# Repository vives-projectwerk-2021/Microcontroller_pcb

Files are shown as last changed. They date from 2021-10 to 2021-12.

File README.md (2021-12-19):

# Microcontroller_pcb

Kicad files for our microcontroller pcb

## Schematic

You can see the updated schematic of our main board in the picture below
Schematic

## Pictures

| Front | Back |
|---|---|
|In this picture you can see the front of the pcb|In this picture you can see the back of the pcb
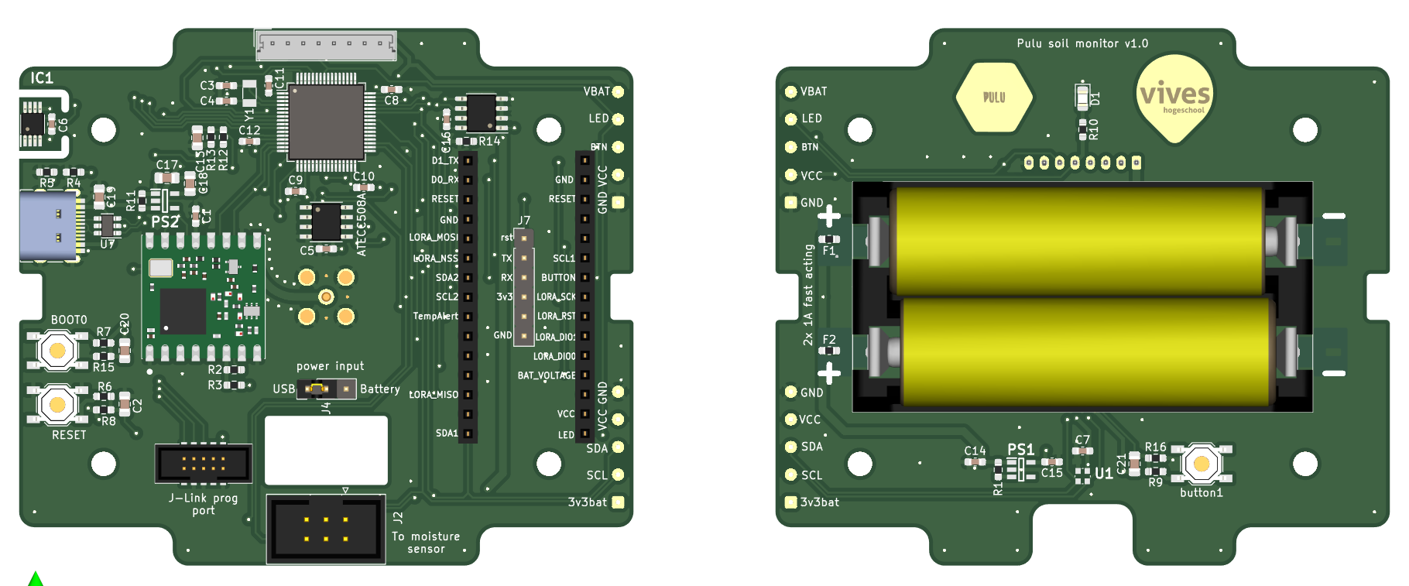
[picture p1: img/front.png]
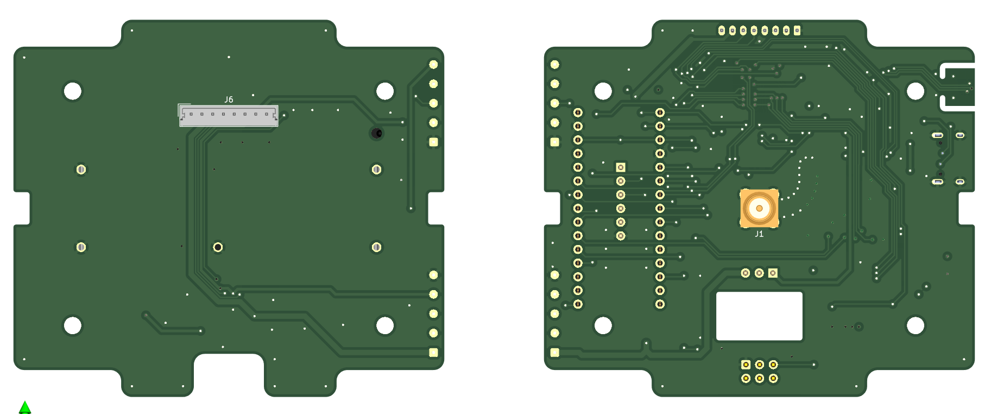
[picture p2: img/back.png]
| |  |

## Components

- STM32L476RGT

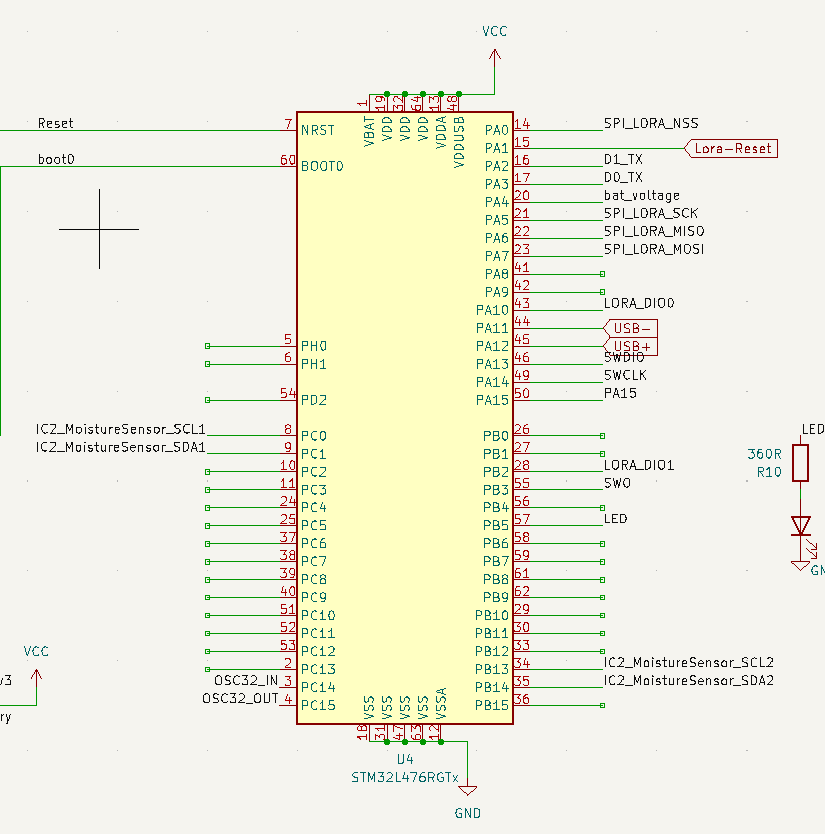
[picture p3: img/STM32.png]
µC


- 32768 Crystal

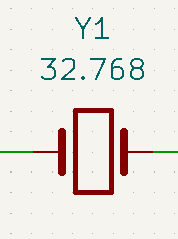
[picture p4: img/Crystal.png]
Crystal


- ESD Protection(USBLC6-2SC6)

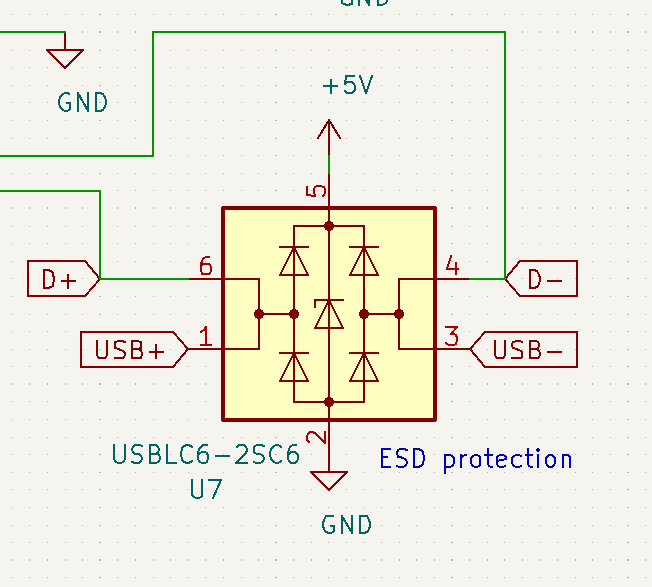
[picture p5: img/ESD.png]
ESD


- L432KC pin layout

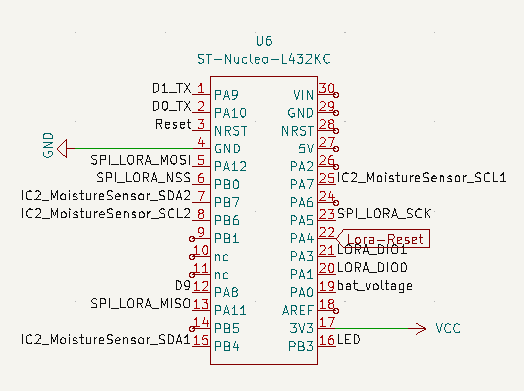
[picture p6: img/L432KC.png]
L432KC


- Cryptochip (ATTEC508A)

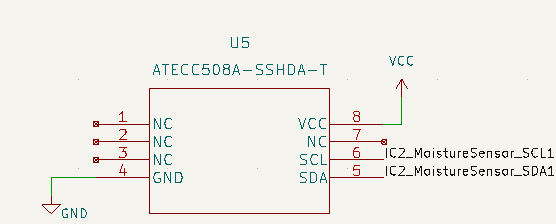
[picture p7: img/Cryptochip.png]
Cryptochip


- Batteryholder(1013)

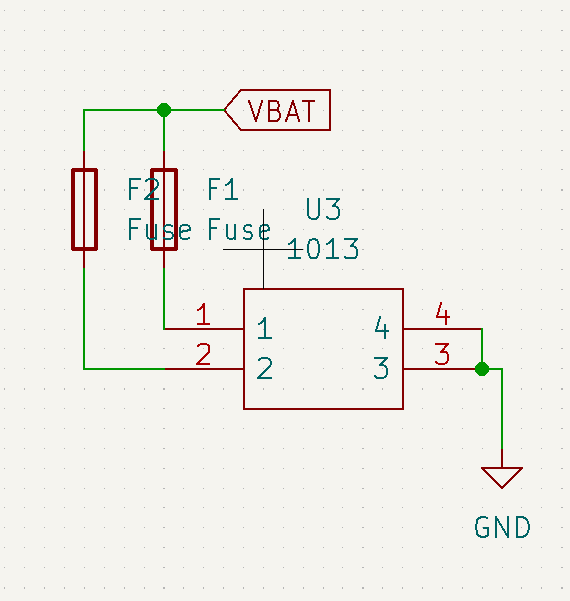
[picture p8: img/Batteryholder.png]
Batteryholder


- LoraModule (RFM95W)

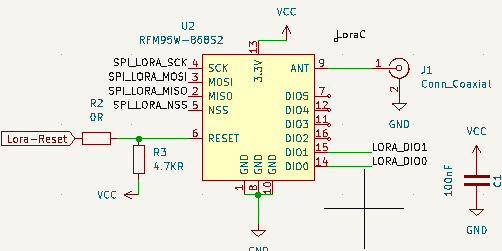
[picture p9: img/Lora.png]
Lora


- Lichtsensor (LTR-329ALS)

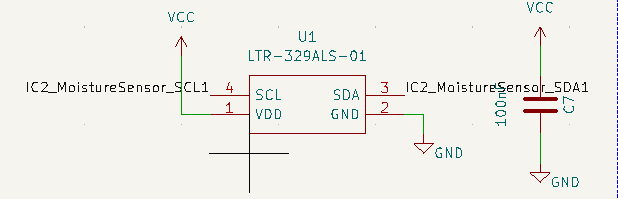
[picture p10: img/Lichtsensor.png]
Lichtsensor


- 2x Button switch SMD

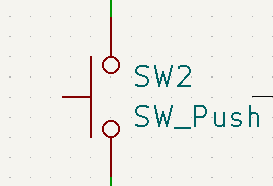
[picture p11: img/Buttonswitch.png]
Button


- 18x 100nF (0603) condensatoren

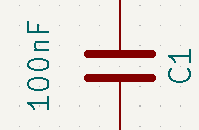
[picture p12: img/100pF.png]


- 2x 4pf (0603) Condensator bij crystal

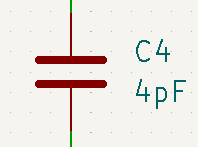
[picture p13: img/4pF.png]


- LED SMD (0805)

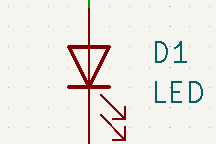
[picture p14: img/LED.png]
LED


- 2x Fuse (0603)

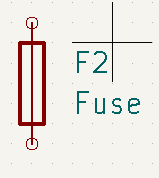
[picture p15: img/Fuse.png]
Fuse


- Temperaturesensor TCN75AVUA713-VAO

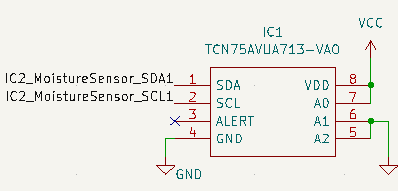
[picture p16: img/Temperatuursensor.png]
Temp


- EEPROM geheugen 24AA64T

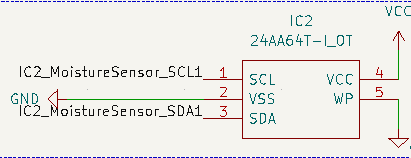
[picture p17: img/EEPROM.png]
EEPROM


- Connector Antenne SMA_Amphenol

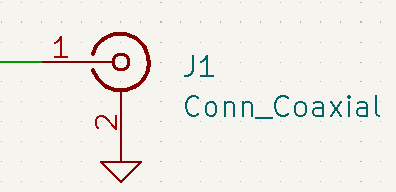
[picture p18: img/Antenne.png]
Antenne


- Connector voor moisture 2x03 2.54mm

Connector

- USB-C Connector 2.0 Type-c-31-m-12

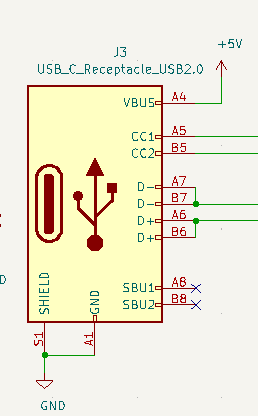
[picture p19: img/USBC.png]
USBC


- Connector voor batterij 1x03 2.54mm

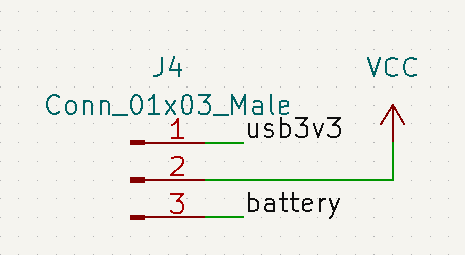
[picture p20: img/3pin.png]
3pin


- 2x Connector Molex 1x08 2.00mm

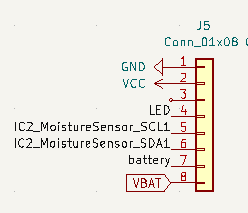
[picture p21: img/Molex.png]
Molex


- SWD Programming port (20021521-00010T1LF)

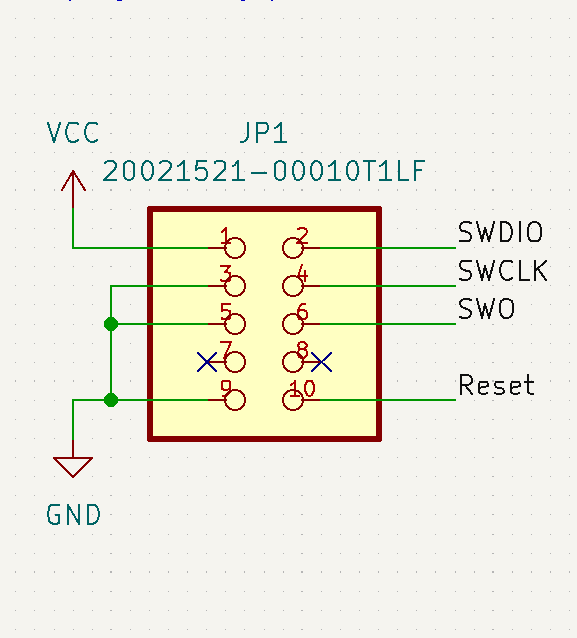
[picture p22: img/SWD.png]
SWD


- 2x LDO (PS1 S-1318B33-M5T1U4)

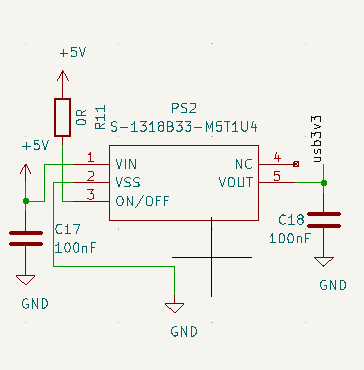
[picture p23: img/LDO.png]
LDO


- 1x 4.7kΩ

R

- 2x 5.1kΩ

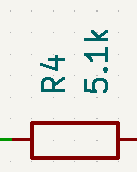
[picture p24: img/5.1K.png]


- 3x 360Ω

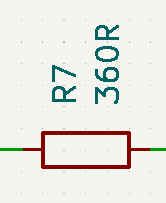
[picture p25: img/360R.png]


- 2x 100kΩ

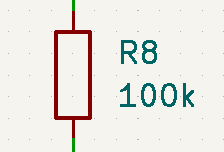
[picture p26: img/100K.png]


- 1x 220kΩ

R

- 1x 330kΩ

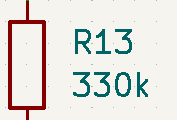
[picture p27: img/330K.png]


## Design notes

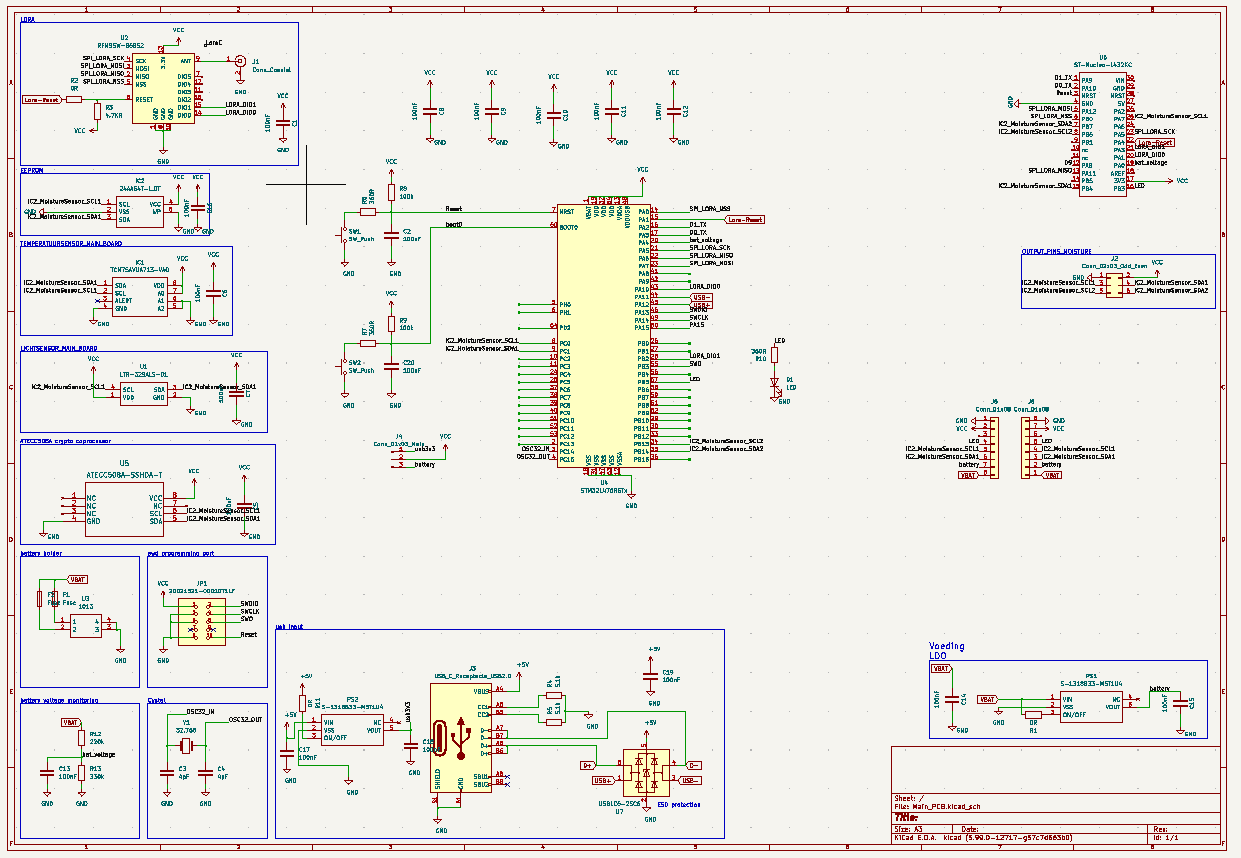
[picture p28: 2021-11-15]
img/Schematic.png

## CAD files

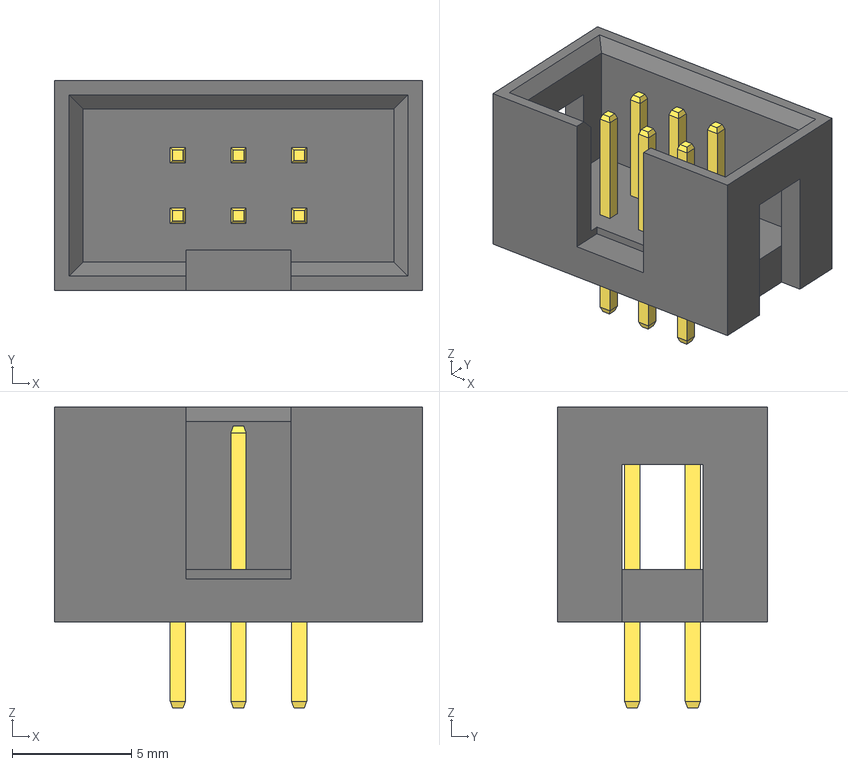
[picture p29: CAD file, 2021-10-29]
3d models/DS1013-6S (IDC-6MS CONNFLY).stp
15.4 x 8.80 x 12.6 mm

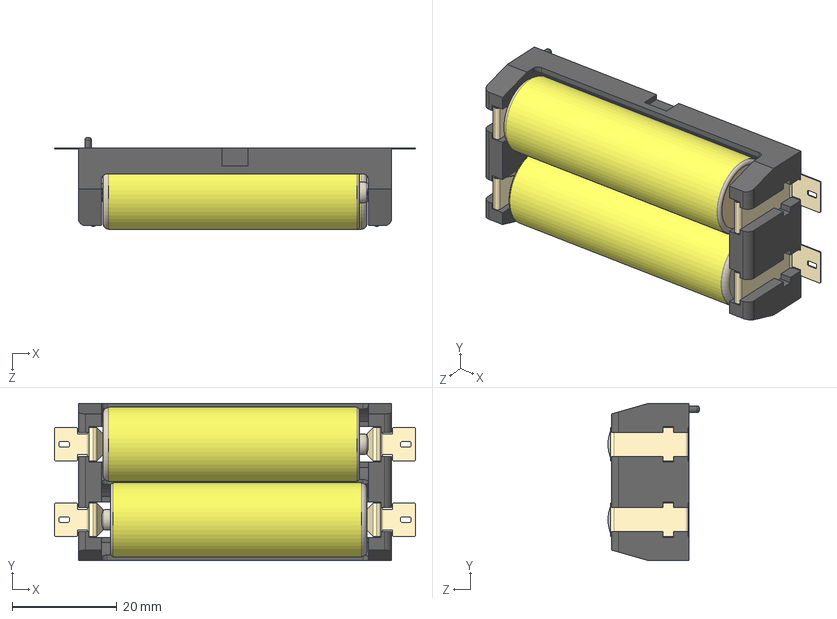
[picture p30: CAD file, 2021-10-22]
3d models/BatteryHolder_Keystone_1012_2xAA.step
69.0 x 30.0 x 17.6 mm
AAx2 SMT 422 Battery Holder
connector x 4
AA Battery_new x 2
bung_battery x 2
grafite_electrode x 2
cap x 2

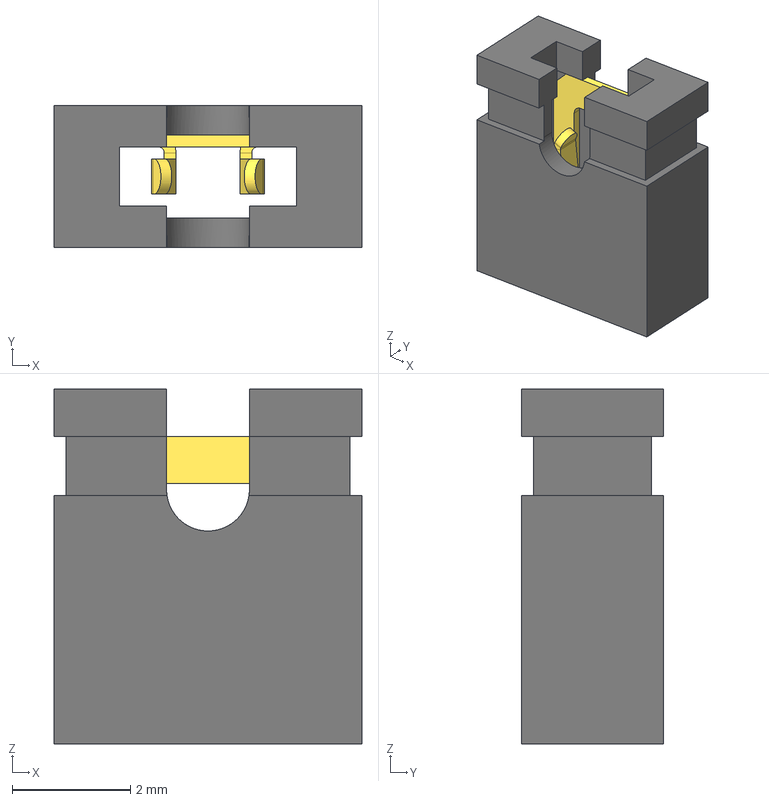
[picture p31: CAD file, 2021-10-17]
3d models/Jumper.step
5.20 x 2.40 x 6.00 mm

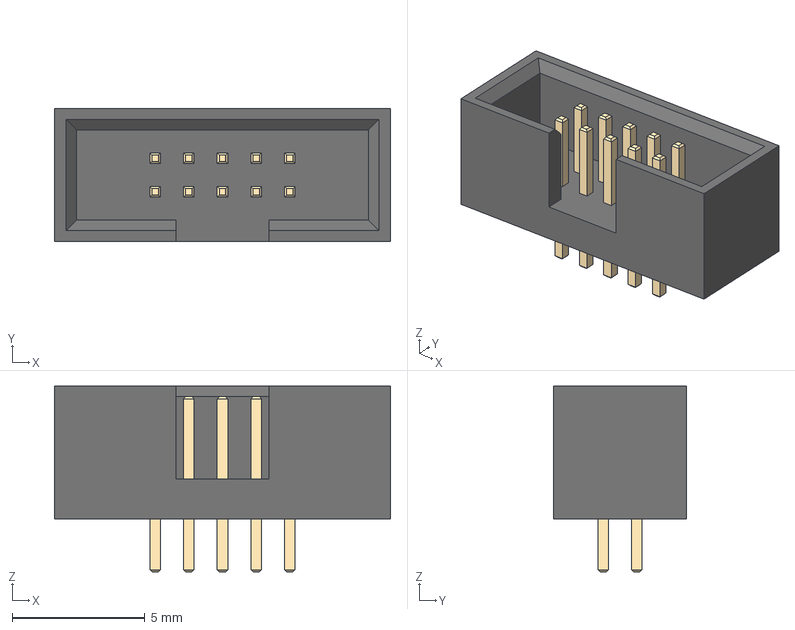
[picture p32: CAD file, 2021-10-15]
3d models/JTAG - 1.27mm - 2x5 v3.step
12.7 x 5.00 x 7.00 mm

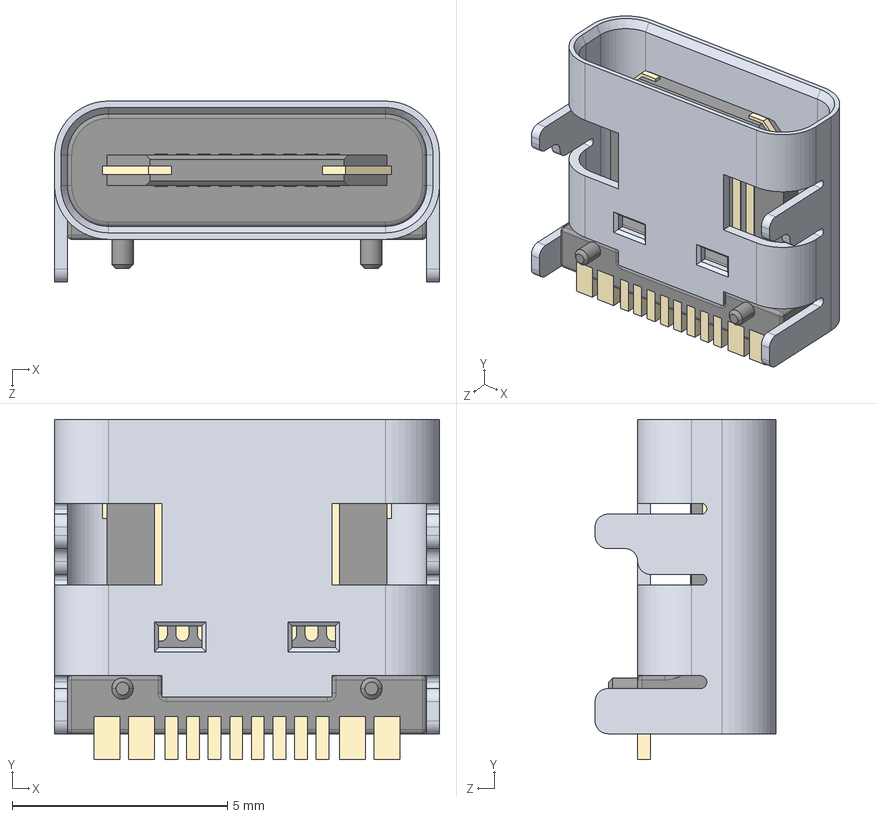
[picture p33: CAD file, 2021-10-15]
3d models/USB Type C Port (SMD Type).STEP
8.94 x 7.90 x 4.20 mm

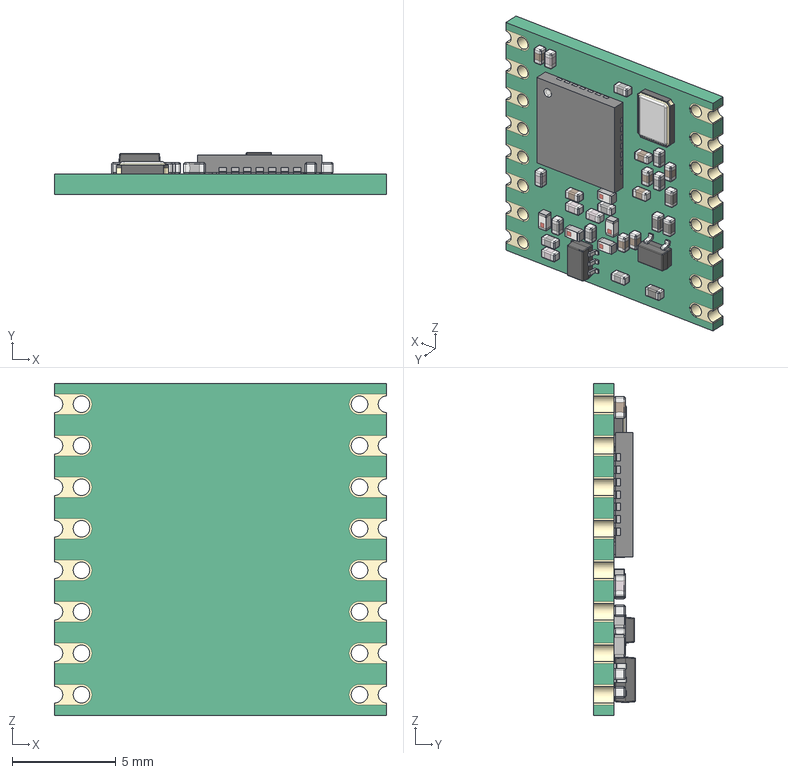
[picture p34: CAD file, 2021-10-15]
3d models/RFM95 LoRa v15.step
16.0 x 2.04 x 16.0 mm
QFN 28
SMD Crystal
CAP 0403 x 8
CAP Ceramic 0403 x 8
Res 0403 x 4
CAP ML 0403 x 5
SOT-323
Inductor SMD 0403 x 5
SOT-363

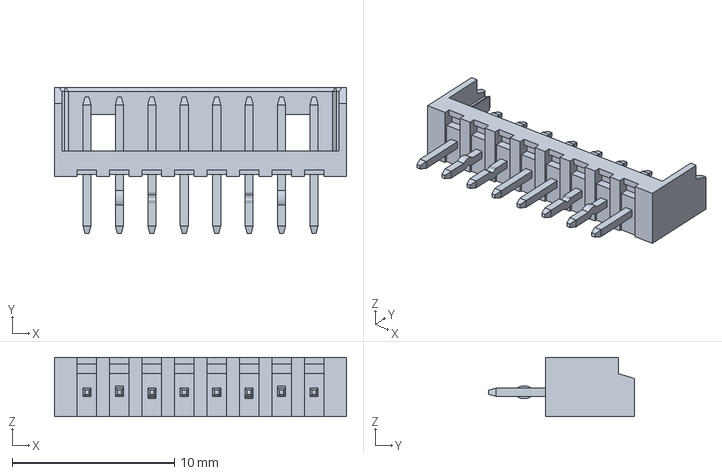
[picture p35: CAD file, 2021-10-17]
3d models/532530870.step
18.0 x 9.00 x 3.65 mm

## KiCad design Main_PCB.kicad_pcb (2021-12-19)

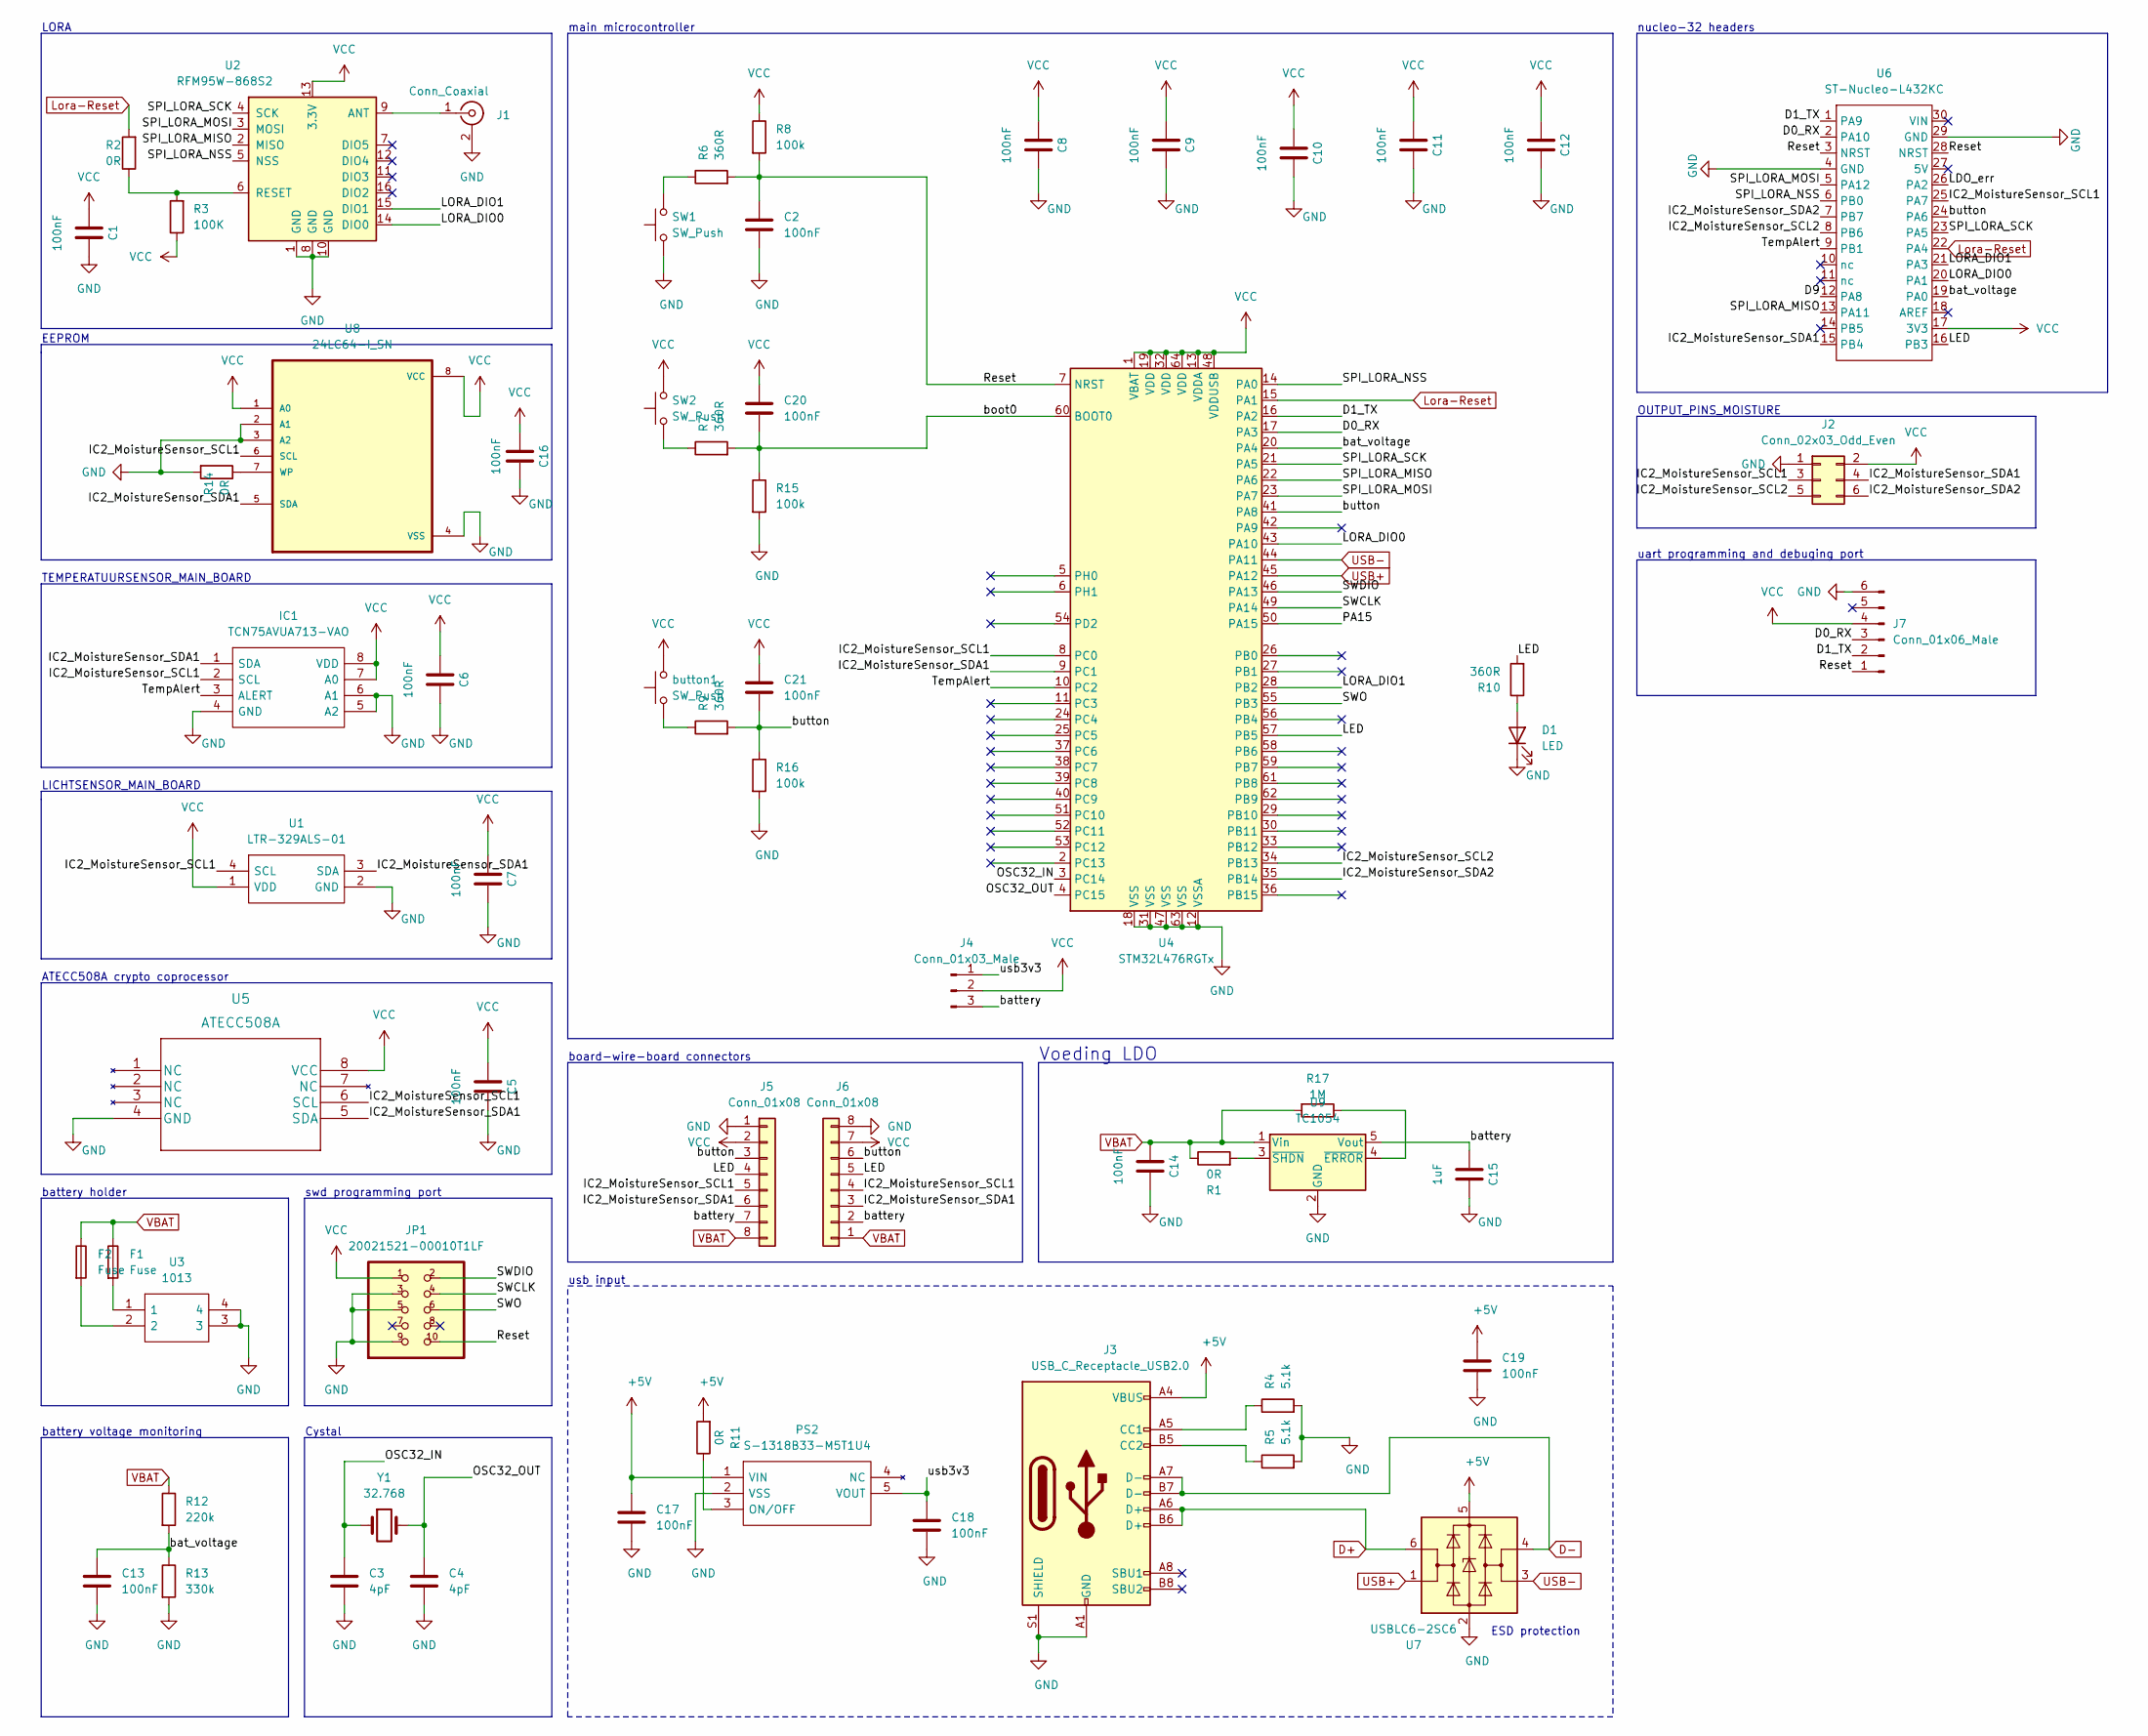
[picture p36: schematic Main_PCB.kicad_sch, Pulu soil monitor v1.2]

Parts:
C1, C2, C5, C6, C7, C8, C9, C10, C11, C12, C13, C14, C16, C17, C18, C19, C20, C21: 100nF; C_0603_1608Metric_Pad1.08x0.95mm_HandSolder
C3, C4: 4pF; C_0603_1608Metric_Pad1.08x0.95mm_HandSolder
C15: 1uF; C_0805_2012Metric_Pad1.18x1.45mm_HandSolder
D1: LED; LED_0805_2012Metric_Pad1.15x1.40mm_HandSolder
F1, F2: Fuse; Fuse_0603_1608Metric_Pad1.05x0.95mm_HandSolder
IC1: TCN75AVUA713-VAO; SOP65P490X110-8N; Manufacturer_Part_Number TCN75AVUA713-VAO; Mouser Part Number 579-TCN75AVUA713-VAO
J1: Conn_Coaxial; SMA_Amphenol_901-144_Vertical
J2: Conn_02x03_Odd_Even; IDC-Header_2x03_P2.54mm_Vertical
J3: USB_C_Receptacle_USB2.0; USB_C_Receptacle_HRO_TYPE-C-31-M-12
J4: Conn_01x03_Male; PinHeader_1x03_P2.54mm_Vertical
J5, J6: Conn_01x08; Molex_Micro-Latch_53253-0870_1x08_P2.00mm_Vertical
J7: Conn_01x06_Male; PinHeader_1x06_P2.54mm_Vertical
JP1: 20021521-00010T1LF
PS2: S-1318B33-M5T1U4; SOT95P275X130-5N; Manufacturer_Part_Number S-1318B33-M5T1U4; Mouser Part Number 628-S-1318B33-M5T1U4
R1, R2, R11, R14: 0R; R_0603_1608Metric_Pad0.98x0.95mm_HandSolder
R3: 100K; R_0603_1608Metric_Pad0.98x0.95mm_HandSolder
R4, R5: 5.1k; R_0603_1608Metric_Pad0.98x0.95mm_HandSolder
R6, R7, R9, R10: 360R; R_0603_1608Metric_Pad0.98x0.95mm_HandSolder
R8, R15, R16: 100k; R_0603_1608Metric_Pad0.98x0.95mm_HandSolder
R12: 220k; R_0603_1608Metric_Pad0.98x0.95mm_HandSolder
R13: 330k; R_0603_1608Metric_Pad0.98x0.95mm_HandSolder
R17: 1M; R_0612_1632Metric_Pad1.18x3.40mm_HandSolder
SW1, SW2: SW_Push; SW_SPST_TL3342
U1: LTR-329ALS-01; LTR329ALS01; Manufacturer_Part_Number LTR-329ALS-01; Mouser Part Number 859-LTR-329ALS-01
U2: RFM95W-868S2; XCVR_RFM95W-868S2
U3: 1013; Manufacturer_Part_Number 1013; Mouser Part Number 534-1013
U4: STM32L476RGTx; LQFP-64_10x10mm_P0.5mm
U5: ATECC508A; ATECC508A-SSHDA-T
U6: ST-Nucleo-L432KC
U7: USBLC6-2SC6; SOT-23-6
U8: 24LC64-I_SN; SOP-8_3.9x4.9mm_P1.27mm
U9: TC1054; SOT-23-5
Y1: 32.768; Crystal_SMD_3215-2Pin_3.2x1.5mm
button1: SW_Push; SW_SPST_TL3342

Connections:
+5V: C17.1, C19.1, J3.A4 (VBUS), J3.A9 (VBUS), J3.B4 (VBUS), J3.B9 (VBUS), PS2.1 (VIN), R11.2, U7.5 (VBUS)
/D0_RX: J7.3, U4.17 (PA3), U6.2 (PA10)
/D1_TX: J7.2, U4.16 (PA2), U6.1 (PA9)
/D9: U6.12 (PA8)
/IC2_MoistureSensor_SCL1: IC1.2 (SCL), J2.3, J5.5, J6.4, U1.4 (SCL), U4.8 (PC0), U5.6 (SCL), U6.25 (PA7), U8.6 (SCL)
/IC2_MoistureSensor_SCL2: J2.5, U4.34 (PB13), U6.8 (PB6)
/IC2_MoistureSensor_SDA1: IC1.1 (SDA), J2.4, J5.6, J6.3, U1.3 (SDA), U4.9 (PC1), U5.5 (SDA), U6.15 (PB4), U8.5 (SDA)
/IC2_MoistureSensor_SDA2: J2.6, U4.35 (PB14), U6.7 (PB7)
/LDO_err: U6.26 (PA2)
/LED: J5.4, J6.5, R10.2, U4.57 (PB5), U6.16 (PB3)
/LORA_DIO0: U2.14 (DIO0), U4.43 (PA10), U6.20 (PA1)
/LORA_DIO1: U2.15 (DIO1), U4.28 (PB2), U6.21 (PA3)
/OSC32_IN: C3.1, U4.3 (PC14), Y1.1
/OSC32_OUT: C4.1, U4.4 (PC15), Y1.2
/PA15: U4.50 (PA15)
/Reset: C2.1, J7.1, JP1.10, R6.2, R8.2, U4.7 (NRST), U6.3 (NRST), U6.28 (NRST)
/SPI_LORA_MISO: U2.2 (MISO), U4.22 (PA6), U6.13 (PA11)
/SPI_LORA_MOSI: U2.3 (MOSI), U4.23 (PA7), U6.5 (PA12)
/SPI_LORA_NSS: U2.5 (NSS), U4.14 (PA0), U6.6 (PB0)
/SPI_LORA_SCK: U2.4 (SCK), U4.21 (PA5), U6.23 (PA5)
/SWCLK: JP1.4, U4.49 (PA14)
/SWDIO: JP1.2, U4.46 (PA13)
/SWO: JP1.6, U4.55 (PB3)
/TempAlert: IC1.3 (ALERT), U4.10 (PC2), U6.9 (PB1)
/bat_voltage: C13.1, R12.2, R13.1, U4.20 (PA4), U6.19 (PA0)
/battery: C15.2, J4.3, J5.7, J6.2, U9.5 (Vout)
/boot0: C20.2, R7.2, R15.1, U4.60 (BOOT0)
/button: C21.2, J5.3, J6.6, R9.2, R16.1, U4.41 (PA8), U6.24 (PA6)
/usb3v3: C18.1, J4.1, PS2.5 (VOUT)
D+: J3.A6 (D+), J3.B6 (D+), U7.6 (I/O1)
D-: J3.A7 (D-), J3.B7 (D-), U7.4 (I/O2)
GND: C1.1, C2.2, C3.2, C4.2, C5.1, C6.1, C7.1, C8.1, C9.1, C10.1, C11.1, C12.1, C13.2, C14.1, C15.1, C16.1, C17.2, C18.2, C19.2, D1.1 (K), IC1.4 (GND), IC1.5 (A2), IC1.6 (A1), J1.2 (Ext), J2.1, J3.A1 (GND), J3.A12 (GND), J3.B1 (GND), J3.B12 (GND), J3.S1 (SHIELD), J5.1, J6.8, J7.6, JP1.3, JP1.5, JP1.9, PS2.2 (VSS), R4.2, R5.2, R13.2, R14.2, R15.2, R16.2, SW1.1, U1.2 (GND), U2.1 (GND), U2.8 (GND), U2.10 (GND), U3.3, U3.4, U4.12 (VSSA), U4.18 (VSS), U4.31 (VSS), U4.47 (VSS), U4.63 (VSS), U5.4 (GND), U6.4 (GND), U6.29 (GND), U7.2 (GND), U8.2 (A1), U8.3 (A2), U8.4 (VSS), U9.2 (GND)
Lora-Reset: R2.2, U4.15 (PA1), U6.22 (PA4)
unnamed: D1.2 (A), R10.1
unnamed: F1.2, U3.1
unnamed: F2.2, U3.2
unnamed: J1.1 (In), U2.9 (ANT)
unnamed: J3.A5 (CC1), R4.1
unnamed: J3.B5 (CC2), R5.1
unnamed: PS2.3 (ON/OFF), R11.1
unnamed: R1.2, U9.3 (~SHDN)
unnamed: R2.1, R3.2, U2.6 (RESET)
unnamed: R6.1, SW1.2
unnamed: R7.1, SW2.1
unnamed: R9.1, button1.1
unnamed: R14.1, U8.7 (WP)
unnamed: R17.1, U9.4 (~ERROR)
USB+: U4.45 (PA12), U7.1 (I/O1)
USB-: U4.44 (PA11), U7.3 (I/O2)
VBAT: C14.2, F1.1, F2.1, J5.8, J6.1, R1.1, R12.1, R17.2, U9.1 (Vin)
VCC: C1.2, C5.2, C6.2, C7.2, C8.2, C9.2, C10.2, C11.2, C12.2, C16.2, C20.1, C21.1, IC1.7 (A0), IC1.8 (VDD), J2.2, J4.2, J5.2, J6.7, J7.4, JP1.1, R3.1, R8.1, SW2.2, U1.1 (VDD), U2.13 (3.3V), U4.1 (VBAT), U4.13 (VDDA), U4.19 (VDD), U4.32 (VDD), U4.48 (VDDUSB), U4.64 (VDD), U5.8 (VCC), U6.17 (3V3), U8.1 (A0), U8.8 (VCC), button1.2

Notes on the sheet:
nucleo-32 headers
swd programming port
Voeding LDO
uart programming and debuging port
OUTPUT_PINS_MOISTURE
EEPROM
battery voltage monitoring
board-wire-board connectors
ESD protection
LORA
battery holder
LICHTSENSOR_MAIN_BOARD
ATECC508A crypto coprocessor
TEMPERATUURSENSOR_MAIN_BOARD
main microcontroller
Cystal
usb input

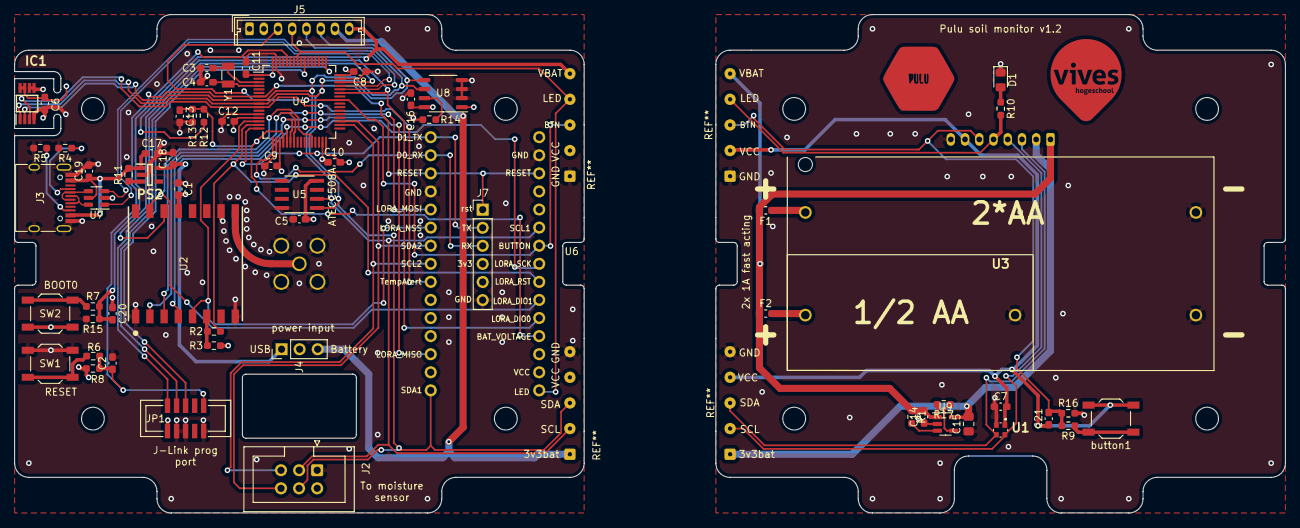
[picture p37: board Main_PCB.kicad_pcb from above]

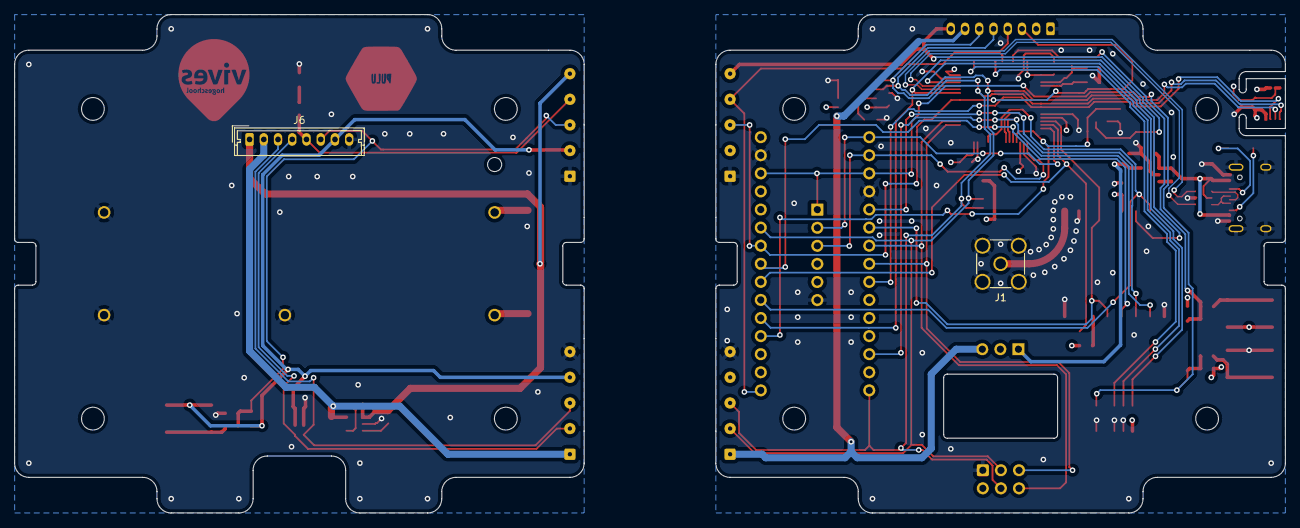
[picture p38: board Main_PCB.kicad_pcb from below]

Board: 4 copper layers, 178.5 x 70.0 mm, 72 parts (2 on the bottom side), 48 nets.

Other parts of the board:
REF1, REF2, REF3, REF4, REF5, REF6, REF7, REF8: MountingHole_3.2mm_M3

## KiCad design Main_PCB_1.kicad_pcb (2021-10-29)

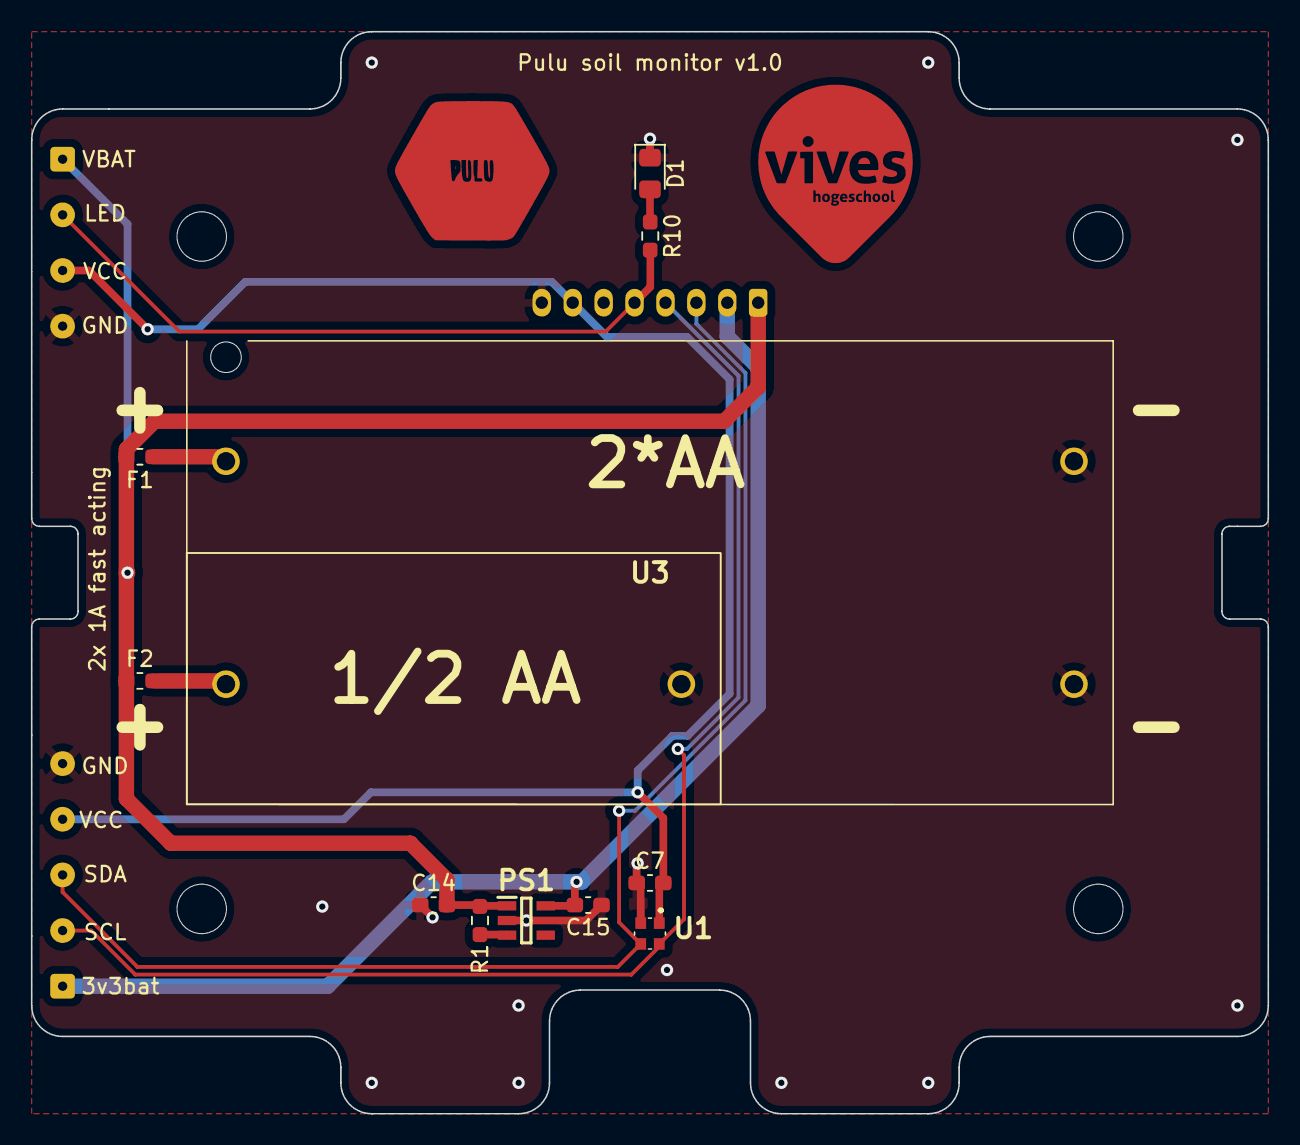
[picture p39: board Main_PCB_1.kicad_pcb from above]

Board: 2 copper layers, 80.0 x 70.0 mm, 16 parts (1 on the bottom side), 11 nets.

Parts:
C7, C14, C15: 100nF; C_0603_1608Metric_Pad1.08x0.95mm_HandSolder
D1: LED; LED_0805_2012Metric_Pad1.15x1.40mm_HandSolder
F1, F2: Fuse; Fuse_0603_1608Metric_Pad1.05x0.95mm_HandSolder
J6: Conn_01x08; Molex_Micro-Latch_53253-0870_1x08_P2.00mm_Vertical
PS1: S-1318B33-M5T1U4; SOT95P275X130-5N
R1: 0R; R_0603_1608Metric_Pad0.98x0.95mm_HandSolder
R10: 360R; R_0603_1608Metric_Pad0.98x0.95mm_HandSolder
REF5, REF6, REF7, REF8: MountingHole_3.2mm_M3
U1: LTR-329ALS-01; LTR329ALS01
U3: 1013

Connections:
/IC2_MoistureSensor_SCL1: J6.4, U1.4 (SCL)
/IC2_MoistureSensor_SDA1: J6.3, U1.3 (SDA)
/LED: J6.5, R10.2
/battery: C15.2, J6.2, PS1.5 (VOUT)
GND: C7.1, C14.1, C15.1, D1.1 (K), J6.8, PS1.2 (VSS), U1.2 (GND), U3.3, U3.4
unnamed: D1.2 (A), R10.1
unnamed: F1.2, U3.1
unnamed: F2.2, U3.2
unnamed: PS1.3 (ON/OFF), R1.2
VBAT: C14.2, F1.1, F2.1, J6.1, PS1.1 (VIN), R1.1
VCC: C7.2, J6.7, U1.1 (VDD)

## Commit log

2021-10-08 started microcontroller pcb added lora, EEPROM, ArduinoHeaders and OUTPUTPINS
    [Main_PCB.kicad_sch]
2021-10-08 fixed microcontroller
    [Main_PCB.kicad_sch]
2021-10-08 added connector for moisture sensor + connected arduino header 2 microcontroller
    [Main_PCB.kicad_sch]
2021-10-08 added battery holder and swd programming port
    [Main_PCB.kicad_pcb, Main_PCB.kicad_sch]
2021-10-11 assigned footprints
    [Main_PCB.kicad_pcb, Main_PCB.kicad_sch]
2021-10-15 did alot of the routing and pcb layout
    [Main_PCB-B_Cu.gbr, Main_PCB-B_Mask.gbr, Main_PCB-B_Paste.gbr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]
2021-10-15 added some 3d files and pcb updates
    [JTAG - 1.27mm - 2x5 v3.step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]
2021-10-16 added images to readme
    [Main_PCB.kicad_pcb]
2021-10-17 finished pcb
    [Jumper.step, Main_PCB.kicad_pcb, Main_PCB.kicad_sch]
2021-10-17 updated b2b connector
    [532530870.step, Main_PCB.kicad_pcb, Main_PCB.kicad_sch]
2021-10-18 made drc complete
    [Main_PCB.kicad_pcb, Main_PCB.kicad_sch]
2021-10-19 updated eeprom footprint
    [Main_PCB.kicad_pcb, Main_PCB.kicad_sch]
2021-10-22 separated pcb desgin into two
    [Main_PCB.kicad_pcb, Main_PCB.kicad_sch]
2021-10-22 added battery 3d model and exported to blender for rendering
    [BatteryHolder_Keystone_1012_2xAA.step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]
2021-10-29 made pcb order ready and ordered on jlcpcb
    [DS1013-6S (IDC-6MS CONNFLY).stp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]
2021-11-15 made BOM
2021-11-20 added general purpose button and updated layout
    [Main_PCB.kicad_pcb]
2021-11-23 updated ldo
    [Main_PCB.kicad_pcb, Main_PCB.kicad_sch]
2021-11-23 updated ldo and fixed git mistake
    [Main_PCB.kicad_pcb, Main_PCB.kicad_sch]
2021-11-23 updated schematic image
    [Main_PCB.kicad_sch]
2021-12-19 updated version names
    [Main_PCB.kicad_pcb, Main_PCB.kicad_sch]

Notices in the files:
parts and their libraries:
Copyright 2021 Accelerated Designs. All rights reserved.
